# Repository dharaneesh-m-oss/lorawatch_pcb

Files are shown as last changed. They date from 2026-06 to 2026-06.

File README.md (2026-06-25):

# LoRa Wearable IoT PCB

A compact, low-power **LoRa-enabled wearable IoT hardware platform** designed using **KiCad**. This PCB was developed by transforming our **Smart India Hackathon (SIH)** prototype into a custom embedded hardware solution.

The board integrates long-range communication, motion sensing, environmental monitoring, GPS connectivity, battery charging, and onboard power management into a compact PCB suitable for wearable and portable IoT applications.

---

## Features

* ESP32-WROOM-32E Microcontroller
* LoRa RA-02 (SX1278) Long Range Communication
* GPS Interface
* MPU6050 6-Axis IMU
* BME280 Temperature, Humidity & Pressure Sensor
* USB Type-C Power Input
* TP4056 Li-ion Battery Charging
* 3.3V Voltage Regulation
* WS2812B Programmable RGB Status LED
* SOS Push Button
* Active Buzzer
* Compact PCB Layout
* Designed in KiCad

---

## Hardware Specifications

| Component | Description |
| --- | --- |
| MCU | ESP32-WROOM-32E |
| LoRa | Ai-Thinker RA-02 (SX1278) |
| Motion Sensor | MPU6050 |
| Environmental Sensor | BME280 |
| Battery Charger | TP4056 |
| Voltage Regulator | AMS1117-3.3 |
| Communication | LoRa + UART + I²C + SPI |
| Power Input | USB Type-C |
| Power Source | 3.7V Li-ion Battery |

---

## Project Structure

```text
LoRa-Wearable-PCB/
│
├── Hardware/
│   ├── Schematic
│   ├── PCB Layout
│   ├── 3D PCB Model
│   └── Libraries
│
├── Images/
│   ├── PCB_3D.png
│   ├── PCB_Top.png
│   ├── PCB_Bottom.png
│   └── Schematic.png
│
├── Manufacturing/
│   ├── Gerber Files
│   ├── Drill Files
│   ├── BOM
│   └── Pick and Place
│
└── README.md
```

---

## Interfaces

### SPI

* LoRa RA-02

### I²C

* MPU6050
* BME280

### UART

* GPS Module

### GPIO

* WS2812B RGB LED
* SOS Button
* Active Buzzer

---

## Software Support

* Arduino IDE
* PlatformIO
* ESP-IDF

---

## Applications

* Smart India Hackathon Projects
* Wearable IoT Devices
* Emergency Communication Systems
* Disaster Management
* Environmental Monitoring
* Asset Tracking
* Wildlife Monitoring
* Smart Agriculture
* Remote Data Acquisition

---

## Design Software

* KiCad

---

## Current Status

* ✅ Schematic Completed
* ✅ PCB Layout Completed
* ✅ 3D PCB Model Completed
* ⏳ PCB Fabrication
* ⏳ Assembly
* ⏳ Firmware Development
* ⏳ Hardware Validation

---

## Future Improvements

* Replace AMS1117 with a low-power LDO
* Add battery protection IC
* Integrate USB-UART programmer
* Optimize RF layout
* Reduce PCB size
* Improve power efficiency

---

## License

This project is released under the MIT License.

---

## Acknowledgement

This project originated as a **Smart India Hackathon (SIH)** prototype and has evolved into a custom PCB through continuous design improvements and embedded hardware development.

---

### If you found this project interesting, consider giving the repository a ⭐.

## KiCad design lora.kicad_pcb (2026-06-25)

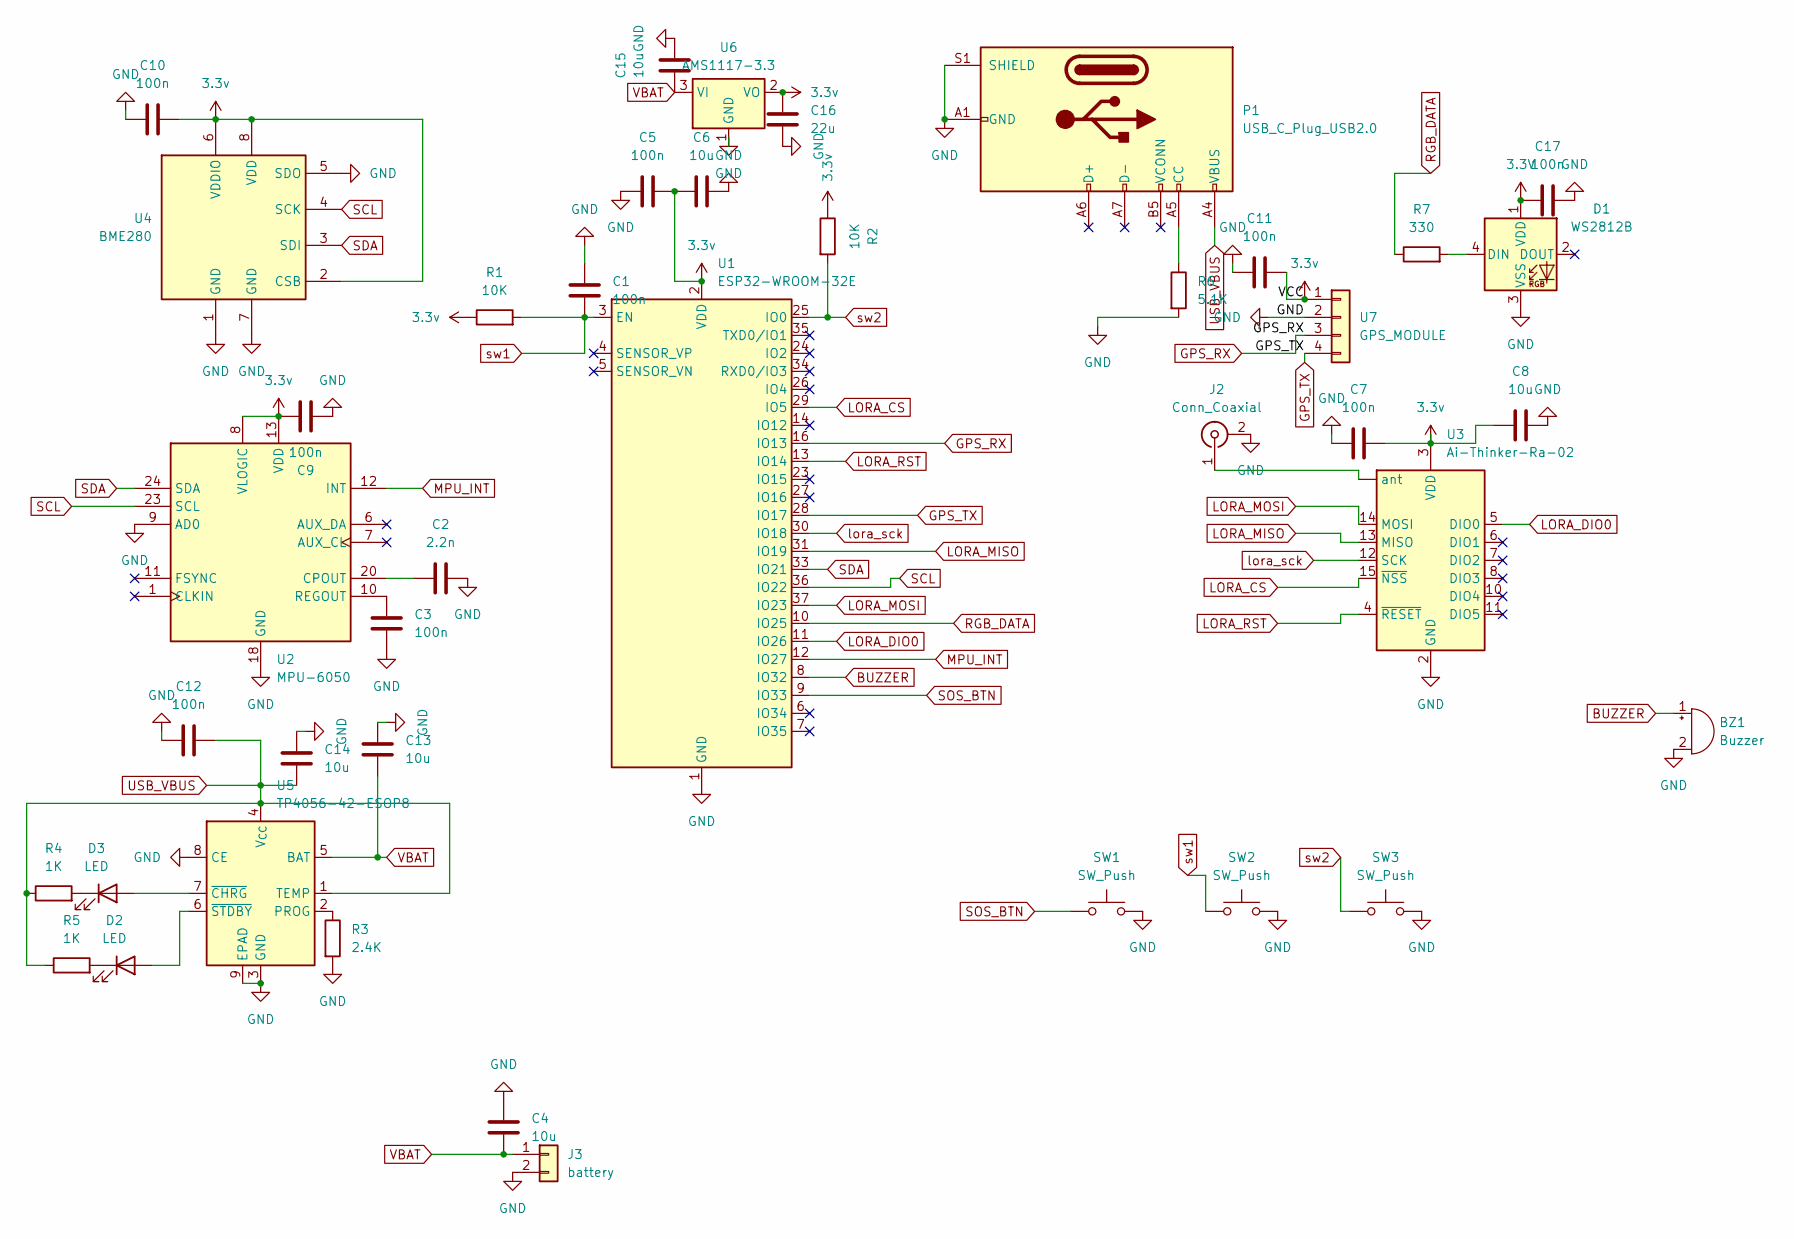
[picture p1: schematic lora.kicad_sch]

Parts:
BZ1: Buzzer; Buzzer_12x9.5RM7.6
C1, C3, C5, C7, C9, C10, C11, C12, C17: 100n; C_0603_1608Metric
C2: 2.2n; C_0603_1608Metric
C4, C6, C8, C13, C14, C15: 10u; C_0805_2012Metric
C16: 22u; C_1206_3216Metric
D1: WS2812B; LED_WS2812B_PLCC4_5.0x5.0mm_P3.2mm
D2, D3: LED; LED_0603_1608Metric
J2: Conn_Coaxial; U.FL_Hirose_U.FL-R-SMT-1_Vertical
J3: battery; JST_PH_B2B-PH-K_1x02_P2.00mm_Vertical
P1: USB_C_Plug_USB2.0; USB_C_Receptacle_HRO_TYPE-C-31-M-12
R1, R2: 10K; R_0603_1608Metric
R3: 2.4K; R_0603_1608Metric
R4, R5: 1K; R_0603_1608Metric
R6: 5.1K; R_0603_1608Metric
R7: 330; R_0603_1608Metric
SW1, SW2, SW3: SW_Push; SW_SPST_TL3342
U1: ESP32-WROOM-32E; ESP32-WROOM-32D
U2: MPU-6050; InvenSense_QFN-24_4x4mm_P0.5mm
U3: Ai-Thinker-Ra-02; Ai-Thinker-Ra-01-LoRa
U4: BME280; Bosch_LGA-8_2.5x2.5mm_P0.65mm_ClockwisePinNumbering
U5: TP4056-42-ESOP8; SOIC-8-1EP_3.9x4.9mm_P1.27mm_EP2.41x3.3mm_ThermalVias
U6: AMS1117-3.3; SOT-223-3_TabPin2
U7: GPS_MODULE; JST_PH_B4B-PH-K_1x04_P2.00mm_Vertical

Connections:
3.3V: C17.2, D1.1 (VDD)
3.3v: C5.2, C6.2, C7.2, C8.2, C9.2, C10.2, C11.2, C16.2, R1.1, R2.1, U1.2 (VDD), U2.8 (VLOGIC), U2.13 (VDD), U3.3 (VDD), U4.2 (CSB), U4.6 (VDDIO), U4.8 (VDD), U6.2 (VO), U7.1
BUZZER: BZ1.1 (+), U1.8 (IO32)
GND: BZ1.2 (-), C1.1, C2.2, C3.2, C4.1, C5.1, C6.1, C7.1, C8.1, C9.1, C10.1, C11.1, C12.1, C13.1, C14.1, C15.1, C16.1, C17.1, D1.3 (VSS), J2.2 (Ext), J3.2, P1.A1 (GND), P1.A12 (GND), P1.B1 (GND), P1.B12 (GND), P1.S1 (SHIELD), R3.2, R6.2, SW1.2, SW2.2, SW3.2, U1.1 (GND), U1.15 (GND), U1.38 (GND), U1.39 (GND), U2.9 (AD0), U2.18 (GND), U3.1 (GND), U3.2 (GND), U3.9 (GND), U3.16 (GND), U4.1 (GND), U4.5 (SDO), U4.7 (GND), U5.3 (GND), U5.8 (CE), U5.9 (EPAD), U6.1 (GND), U7.2
GPS_RX: U1.16 (IO13), U7.3
GPS_TX: U1.28 (IO17), U7.4
LORA_CS: U1.29 (IO5), U3.15 (~NSS)
LORA_DIO0: U1.11 (IO26), U3.5 (DIO0)
LORA_MISO: U1.31 (IO19), U3.13 (MISO)
LORA_MOSI: U1.37 (IO23), U3.14 (MOSI)
LORA_RST: U1.13 (IO14), U3.4 (~RESET)
MPU_INT: U1.12 (IO27), U2.12 (INT)
unnamed: D1.4 (DIN), R7.2
unnamed: D2.2 (A), U5.6 (~STDBY)
unnamed: D2.1 (K), R5.2
unnamed: D3.2 (A), U5.7 (~CHRG)
unnamed: D3.1 (K), R4.2
unnamed: J2.1 (In), U3. (ant)
unnamed: P1.A5 (CC), R6.1
unnamed: C2.1, U2.20 (CPOUT)
unnamed: C3.1, U2.10 (REGOUT)
unnamed: R3.1, U5.2 (PROG)
RGB_DATA: R7.1, U1.10 (IO25)
SCL: U1.36 (IO22), U2.23 (SCL), U4.4 (SCK)
SDA: U1.33 (IO21), U2.24 (SDA), U4.3 (SDI)
SOS_BTN: SW1.1, U1.9 (IO33)
USB_VBUS: C12.2, C14.2, P1.A4 (VBUS), P1.A9 (VBUS), P1.B4 (VBUS), P1.B9 (VBUS), R4.1, R5.1, U5.1 (TEMP), U5.4 (V_{CC})
VBAT: C4.2, C13.2, C15.2, J3.1, U5.5 (BAT), U6.3 (VI)
lora_sck: U1.30 (IO18), U3.12 (SCK)
sw1: C1.2, R1.2, SW2.1, U1.3 (EN)
sw2: R2.2, SW3.1, U1.25 (IO0)

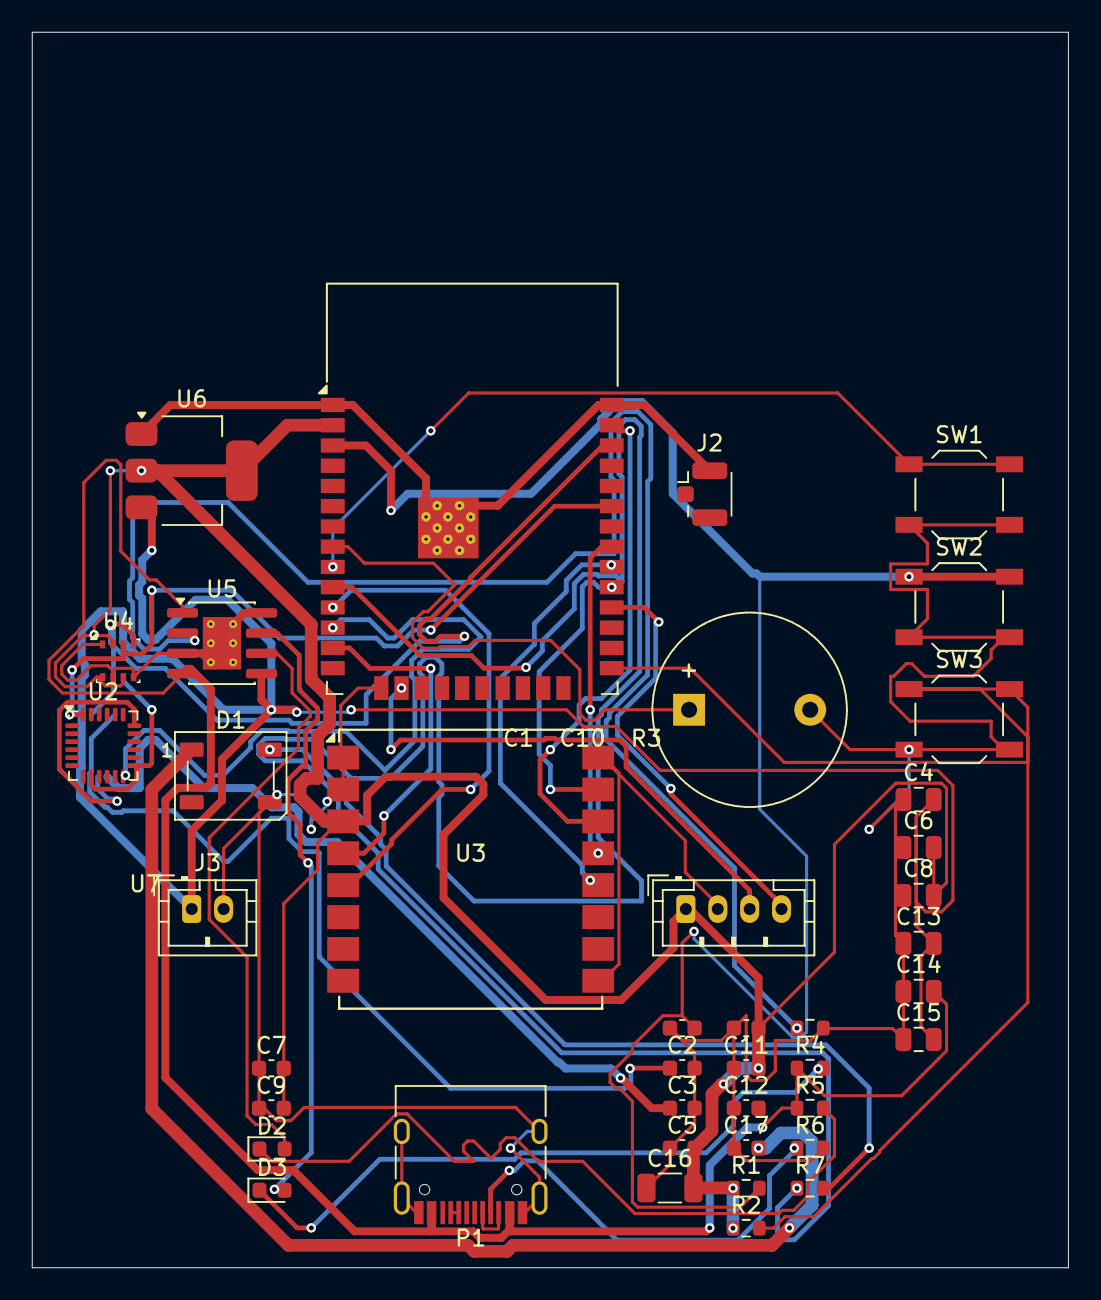
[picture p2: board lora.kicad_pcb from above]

Board: 2 copper layers, 65.0 x 77.5 mm, 41 parts (0 on the bottom side), 30 nets.
